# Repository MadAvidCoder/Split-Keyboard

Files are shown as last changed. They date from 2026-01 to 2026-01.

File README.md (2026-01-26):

# Split Keyboard
An ergonomic, wireless, split, low-profile keyboard I made for [Hack Club](https://hackclub.com/) [Blueprint](https://blueprint.hackclub.com/r/43?ref=r)! It is inspired by the Lily58 layout, but with column-staggering better optimised for my hands. It also features a thumb cluster designed for better ergonomics. Having recently started using a Mechcanical Keyboard, I was keen to design a Split Keyboard that was easy to transition to, so I elected to include a number row, and an additional 'function' column on each half.

You can read about my development journey [here](https://blueprint.hackclub.com/projects/10297).

render

## Key Features
- Wireless
- Split
- Customisable ZMK Firmware
- Column Staggered
- 54 Keys
- Thumb Clusters
- Low Profile Choc Switches
- RGB Backlight

## PCB
I designed the PCB using KiCad. I kept it simple, with only 2 layers. The two halves are (mostly) mirror-images of each other, and I used hierarchical sheets to easily keep the design matching.

### Schematic
schematic

### PCB Design
| Left | Right |
|---|---|
|||

## Firmware
I am using [ZMK Firmware](https://zmk.dev/) for this keyboard. The configuration files are in their own repo, linked to the `firmware` directory. I chose to keep the keymap simple, to make it easy to transition to from a standard keyboard. I have also included minimal extra features and config, as I want to experiment with that side of things, once I have actually built it.

## Case
I designed the case for the keyboard in Autodesk Fusion 360. It is a fairly simple design, which secures the PCB via 5 screws, and has a top plate to hold it all in place. The top half is secured with a number of locating pins. The two halves of the case are nearly identical, except for different placement of the capacitor cutout.

The case also features a cutout and location for the LiPo battery, so it can be easily secured. USB and charging access is via the edge above the thumb cluster.

|Top|Bottom|
|---|---|
|||

### Render
render

### Keycaps
To ensure they work well, I am using keycaps designed by other people. For the main keycaps, I am using the [LPX profile keycaps](https://github.com/levpopov/LPX), designed by [levpopov](https://github.com/levpopov).

For the thumb clusters, I have selected the [Choc Louder Keycaps](https://www.printables.com/model/1066117-choc-louder-keycaps-choc-and-mx-spacing) by [kooziecup](https://www.printables.com/@koozie). The dimpled profile should make them more comfortable for the thumbs to rest on.

## BOM
A more detailed csv BOM can be found in [BOM.csv](/BOM.csv). All prices are in USD, and rounded to 2 decimal places (although the total is based on un-rounded prices).

In some cases, items may have higher quantities than are actually needed, due to MOQ. However, I have done thorough research to ensure that these still work out as the cheapest option.

| Item | Qty. | Price (USD) | Ext. Price (USD) | Link |
|---|---|---|---|---|
| PCB | 1 | 12.55 | 12.55 | https://jlcpcb.com/ |
| Battery | 2 | 5.80 | 11.60 | https://ecocell.com.au/product/lipo-600-503040/ |
| nice!nano | 2 | 4.55 | 9.10 | https://www.aliexpress.com/item/1005007266900944.html |
| Hotswap Sockets | 70 | 0.11 | 7.70 | https://www.aliexpress.com/item/1005009312876316.html |
| Switches | 60 | 0.46 | 27.60 | https://www.aliexpress.com/item/1005008751312031.html |
| SK6812-MINI-E | 55 | 0.07 | 3.85 | https://www.lcsc.com/product-detail/C5149201.html |
| DMBJ PNLS8040-100M 10UH | 5 | 0.11 | 0.55 | https://www.lcsc.com/product-detail/C2849554.html |
| 100nF Capacitor | 100  | 0.01 | 1.00 | https://www.lcsc.com/product-detail/C49678.html |
| 10uF Capacitor | 10 | 0.02 | 0.20 | https://www.lcsc.com/product-detail/C32635.html |
| 22uF Capacitor | 10 | 0.02 | 0.20 | https://www.lcsc.com/product-detail/C98190.html |
| 470uF Capacitor | 10 | 0.04 | 0.40 | https://www.lcsc.com/product-detail/C2858856.html |
| 1N5819 Diode | 100  | 0.01 | 1.00 | https://www.lcsc.com/product-detail/C963381.html |
| SS34 Schottky Diode | 10 | 0.03 | 0.30 | https://www.lcsc.com/product-detail/C842788.html |
| 806k Resistor | 20 | <0.01 | 0.09 | https://www.lcsc.com/product-detail/C865659.html |
| 2M Resistor | 100  | <0.01 | 0.25 | https://www.lcsc.com/product-detail/C26112.html |
| 470R Resistor | 100  | <0.01 | 0.17 | https://www.lcsc.com/product-detail/C2907267.html |
| 2k Resistor | 100  | <0.01 | 0.18 | https://www.lcsc.com/product-detail/C2907248.html |
| 10k Resistor | 10 | 0.04 | 0.40 | https://www.lcsc.com/product-detail/C319942.html |
| 73.2k Resistor | 50 | 0.01 | 0.50 | https://www.lcsc.com/product-detail/C422816.html |
| 330R Resistor | 100  | <0.01 | 0.13 | https://www.lcsc.com/product-detail/C2907321.html |
| DW01A | 20 | 0.02 | 0.40 | https://www.lcsc.com/product-detail/C18164398.html |
| FS8205 | 10 | 0.05 | 0.50 | https://www.lcsc.com/product-detail/C2830320.html |
| MT3608 | 10 | 0.06 | 0.60 | https://www.lcsc.com/product-detail/C84817.html |
| LCSC Shipping | 1 | 12.72 | 12.72 | https://www.lcsc.com/ |
| EcoCell Shipping | 1 | 2.78 | 2.78 | https://ecocell.com.au/ |
| | | | | |
| **TOTAL** | | | | **$93.95 (USD)** |

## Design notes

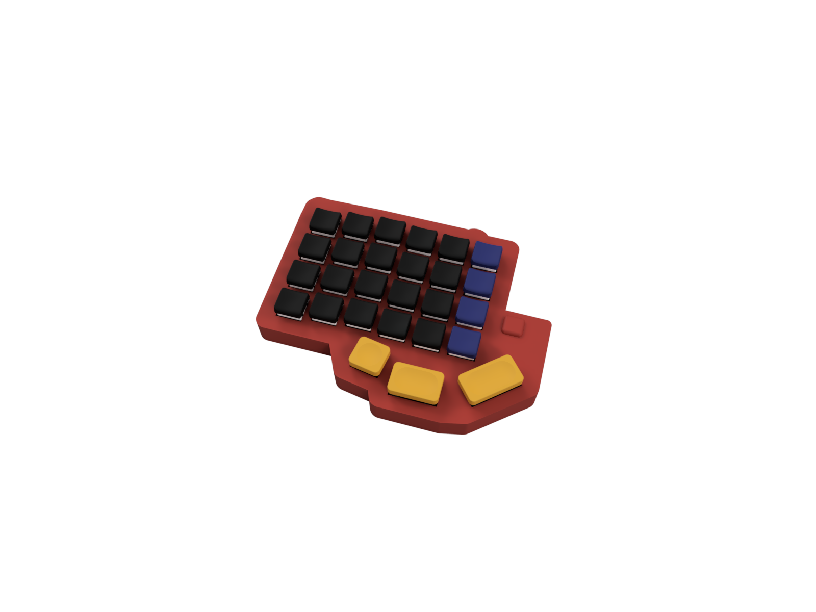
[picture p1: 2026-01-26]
case/render.png

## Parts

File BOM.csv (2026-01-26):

Part Name | Supplier | Link | Req. Qty | Total Qty | Unit Price | Total | Product Description
PCB | JLCPCB | https://jlcpcb.com/ | 1 | 5 | $2.51 | $12.55 | The PCB for the project
LiPo Battery | EcoCell | https://ecocell.com.au/product/lipo-600-503040/ | 2 | 2 | $5.80 | $11.60 | Rechargeable battery to power the keyboard
nice!nano | AliExpress | https://www.aliexpress.com/item/1005007266900944.html | 2 | 2 | $4.55 | $9.10 | Main microcontroller for the board (cheaper than xiao)
Hotswap Sockets | AliExpress | https://www.aliexpress.com/item/1005009312876316.html | 54 | 70 | $0.11 | $7.70 | Hotswap sockets, which make soldering easier
Switches | AliExpress | https://www.aliexpress.com/item/1005008751312031.html | 54 | 60 | $0.46 | $27.60 | There are a number of other options, but these seem the cheapest/best
SK6812-MINI-E | LCSC | https://www.lcsc.com/product-detail/C5149201.html | 54 | 55 | $0.07 | $3.85 | LED Backlight (reverse-mounted)
DMBJ PNLS8040-100M 10UH | LCSC | https://www.lcsc.com/product-detail/C2849554.html | 2 | 5 | $0.11 | $0.55 | Inductors for the 5V regulator
100nF Capacitor | LCSC | https://www.lcsc.com/product-detail/C49678.html | 56 | 100 | $0.01 | $1.00 | Used in various places, mostly as decoupling capacitors for the LEDs
10uF Capacitor | LCSC | https://www.lcsc.com/product-detail/C32635.html | 2 | 10 | $0.02 | $0.20 | Decoupling Capacitor for the battery protection ic
22uF Capacitor | LCSC | https://www.lcsc.com/product-detail/C98190.html | 4 | 10 | $0.02 | $0.20 | Decoupling capacitors for the 5V Boost converter
470uF Capacitor | LCSC | https://www.lcsc.com/product-detail/C2858856.html | 2 | 10 | $0.04 | $0.40 | Bulk Capacitor for the LEDs
1N5819 Diode | LCSC | https://www.lcsc.com/product-detail/C963381.html | 54 | 100 | $0.01 | $1.00 | Diodes for the keyboard matrix
SS34 Schottky Diode | LCSC | https://www.lcsc.com/product-detail/C842788.html | 2 | 10 | $0.03 | $0.30 | Schottky Diodes for low power loss in the boost converter
806k Resistor | LCSC | https://www.lcsc.com/product-detail/C865659.html | 2 | 20 | $0.00 | $0.00 | For the voltage divider
2M Resistor | LCSC | https://www.lcsc.com/product-detail/C26112.html | 2 | 100 | $0.00 | $0.00 | For the voltage divider
470R Resistor | LCSC | https://www.lcsc.com/product-detail/C2907267.html | 2 | 100 | $0.00 | $0.00 | For the BMS circuitry. Ordering so many because it works out far cheaper than other options
2k Resistor | LCSC | https://www.lcsc.com/product-detail/C2907248.html | 2 | 100 | $0.00 | $0.00 | For the BMS current detection. Ditto above as to why 100
10k Resistor | LCSC | https://www.lcsc.com/product-detail/C319942.html | 2 | 10 | $0.04 | $0.40 | Has to be low tolerance, for the 5v boost converter feedback
73k2 Resistor | LCSC | https://www.lcsc.com/product-detail/C422816.html | 2 | 50 | $0.01 | $0.50 | Has to be low tolerance, and they only had a few options, which had high MOQ
330R Resistor | LCSC | https://www.lcsc.com/product-detail/C2907321.html | 2 | 100 | $0.00 | $0.00 | For the LED Data lines, ordering a ton because its cheaper than one with low MOQ
DW01A | LCSC | https://www.lcsc.com/product-detail/C18164398.html | 2 | 20 | $0.02 | $0.40 | Battery Management IC (20 bc MOQ)
FS8205 | LCSC | https://www.lcsc.com/product-detail/C2830320.html | 2 | 10 | $0.05 | $0.50 | MOSFETs for the BMS
MT3608 | LCSC | https://www.lcsc.com/product-detail/C84817.html | 2 | 10 | $0.06 | $0.60 | 5V Boost Converter
LCSC Shipping | LCSC | https://www.lcsc.com/ | 1 | 1 | $12.72 | $12.72 | Shipping costs for all LCSC parts
EcoCell Shipping | EcoCell | https://ecocell.com.au/ | 1 | 1 | $2.78 | $2.78 | Shipping costs for all EcoCell parts
TOTAL |  |  |  |  |  | $93.95

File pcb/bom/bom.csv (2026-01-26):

Reference | Qty | Value | DNP | Exclude from BOM | Exclude from Board | Footprint | Datasheet
C1,C2,C9,C10,C11,C12,C13,C14,C15,C16,C17,C18,C19,C20,C21,C22,C23,C24,C25,C26,C27,C28,C29,C30,C31,C32,C33,C34,C35,C36,C37,C38,C39,C40,C41,C42,C43,C44,C45,C46,C47,C48,C49,C50,C51,C52,C53,C54,C55,C56,C60,C61,C62,C66,C67,C68 | 56 | 100n |  |  |  | Capacitor_SMD:C_0805_2012Metric_Pad1.18x1.45mm_HandSolder | ~
C3,C4 | 2 | 10u |  |  |  | Capacitor_SMD:C_0805_2012Metric_Pad1.18x1.45mm_HandSolder | ~
C5,C6,C7,C8 | 4 | 22u |  |  |  | Capacitor_SMD:C_0805_2012Metric_Pad1.18x1.45mm_HandSolder | ~
C57,C58 | 2 | 470u |  |  |  | Capacitor_SMD:CP_Elec_6.3x7.7 | ~
D1,D2,D3,D4,D5,D6,D7,D8,D9,D10,D11,D12,D13,D14,D15,D16,D17,D18,D19,D20,D21,D22,D23,D24,D25,D26,D27,D28,D29,D30,D31,D32,D33,D34,D35,D36,D37,D38,D39,D40,D41,D42,D43,D44,D45,D46,D47,D48,D49,D50,D51,D52,D53,D54 | 54 | D |  |  |  | Diode_SMD:D_SOD-123 | ~
D55,D56 | 2 | SS34 |  |  |  | Diode_SMD:D_SMA | https://www.vishay.com/docs/88751/ss32.pdf
H1,H2,H15 | 3 | MountingHole |  | Excluded from BOM |  | Panelization:mouse-bite-3mm-slot | ~
H3,H4,H5,H6,H7,H8,H9,H10,H11,H12 | 10 | MountingHole |  | Excluded from BOM |  | MountingHole:MountingHole_3.2mm_M3 | ~
L1,L2 | 2 | PNLS8040-100M 10UH |  |  |  | Inductor_SMD:L_Cenker_CKCS8040 | ~
LED1,LED2,LED3,LED4,LED5,LED6,LED7,LED8,LED9,LED10,LED11,LED12,LED25,LED26,LED27,LED28,LED29,LED30,LED31,LED32,LED33,LED34,LED35,LED36,LED52,LED53,LED54,LED58,LED59,LED60 | 30 | choc_SK6812MINI-E |  |  |  | PCM_marbastlib-choc:LED_choc_6028R
LED13,LED14,LED15,LED16,LED17,LED18,LED19,LED20,LED21,LED22,LED23,LED24,LED37,LED38,LED39,LED40,LED41,LED42,LED43,LED44,LED45,LED46,LED47,LED48 | 24 | choc_SK6812MINI-E |  |  |  | PCM_marbastlib-choc:LED_choc_6028R-ROT
R1,R2 | 2 | 806k |  |  |  | Resistor_SMD:R_0805_2012Metric_Pad1.20x1.40mm_HandSolder | ~
R3,R4 | 2 | 2M |  |  |  | Resistor_SMD:R_0805_2012Metric_Pad1.20x1.40mm_HandSolder | ~
R5,R6 | 2 | 470R |  |  |  | Resistor_SMD:R_0805_2012Metric_Pad1.20x1.40mm_HandSolder | ~
R7,R8 | 2 | 2k |  |  |  | Resistor_SMD:R_0805_2012Metric_Pad1.20x1.40mm_HandSolder | ~
R9,R10 | 2 | 10k |  |  |  | Resistor_SMD:R_0805_2012Metric_Pad1.20x1.40mm_HandSolder | ~
R11,R12 | 2 | 73k2 |  |  |  | Resistor_SMD:R_0805_2012Metric_Pad1.20x1.40mm_HandSolder | ~
R13,R14 | 2 | 330R |  |  |  | Resistor_SMD:R_0805_2012Metric_Pad1.20x1.40mm_HandSolder | ~
SW1,SW2,SW3,SW4,SW5,SW6,SW7,SW8,SW9,SW10,SW11,SW12,SW13,SW14,SW15,SW16,SW17,SW18,SW19,SW20,SW21,SW22,SW23,SW24,SW25,SW26,SW27,SW28,SW29,SW30,SW31,SW32,SW33,SW34,SW35,SW36,SW37,SW38,SW39,SW40,SW41,SW42,SW43,SW44,SW45,SW46,SW47,SW48,SW53,SW54 | 50 | SW_Push |  |  |  | PCM_marbastlib-choc:SW_choc_v1_HS_CPG135001S30_1u | ~
SW49,SW50 | 2 | SW_Push |  |  |  | marbastlib-choc:SW_choc_v1_HS_CPG135001S30_1.75u | ~
SW51,SW52 | 2 | SW_Push |  |  |  | marbastlib-choc:SW_choc_v1_HS_CPG135001S30_1.5u | ~
TP1,TP2 | 2 | BAT |  |  |  | TestPoint:TestPoint_Pad_D2.0mm | ~
TP3,TP4 | 2 | GND |  |  |  | TestPoint:TestPoint_Pad_D2.0mm | ~
U3,U4 | 2 | DW01A |  |  |  | Package_TO_SOT_SMD:SOT-23-6 | https://hmsemi.com/downfile/DW01A.PDF
U5,U6 | 2 | FS8205 |  |  |  | Package_TO_SOT_SMD:SOT-23-6 | https://datasheet.lcsc.com/szlcsc/Fortune-Semicon-FS8205_C32254.pdf
U7,U8 | 2 | MT3608 |  |  |  | Package_TO_SOT_SMD:SOT-23-6 | https://www.olimex.com/Products/Breadboarding/BB-PWR-3608/resources/MT3608.pdf
U9,U10 | 2 | nice_nano |  | Excluded from BOM |  | PCM_marbastlib-xp-promicroish:nice_nano_AH_USBup | https://nicekeyboards.com/docs/nice-nano/pinout-schematic

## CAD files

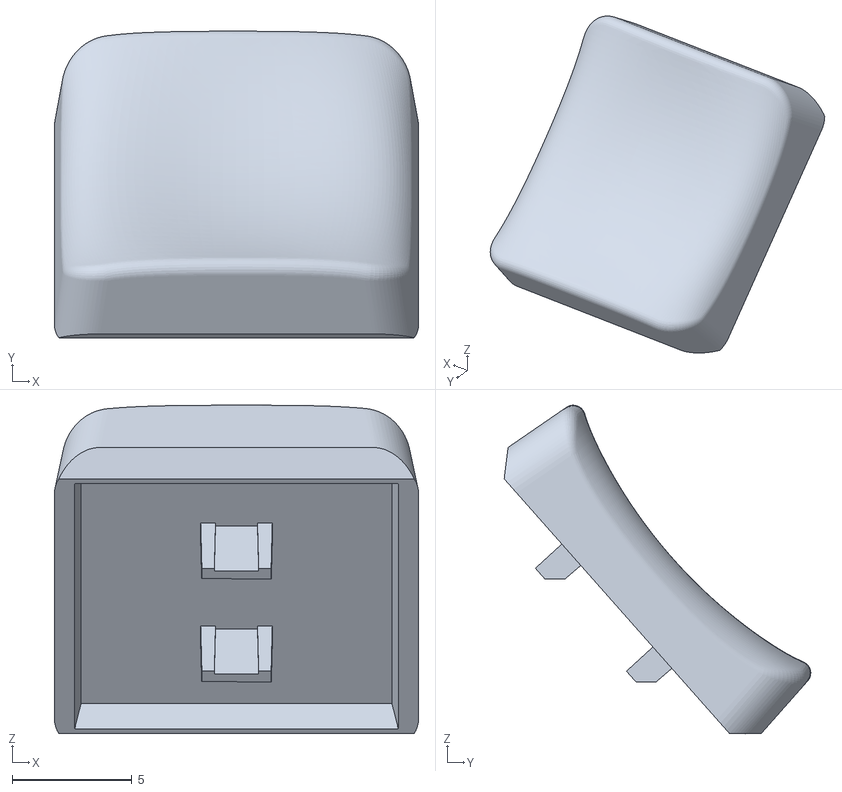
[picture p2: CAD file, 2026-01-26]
case/Main Keycap.stl
15.2 x 12.8 x 13.7

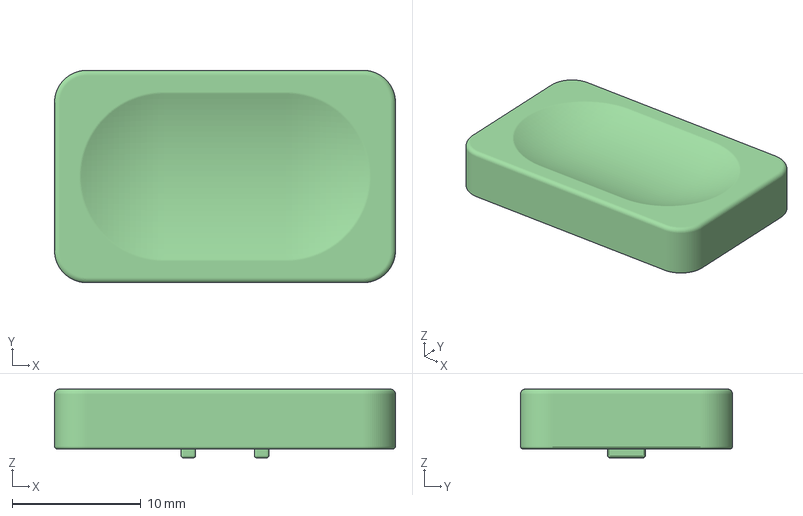
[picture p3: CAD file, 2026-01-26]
case/Thumb Keycap - 1.5u.3mf
26.5 x 16.5 x 5.35 mm

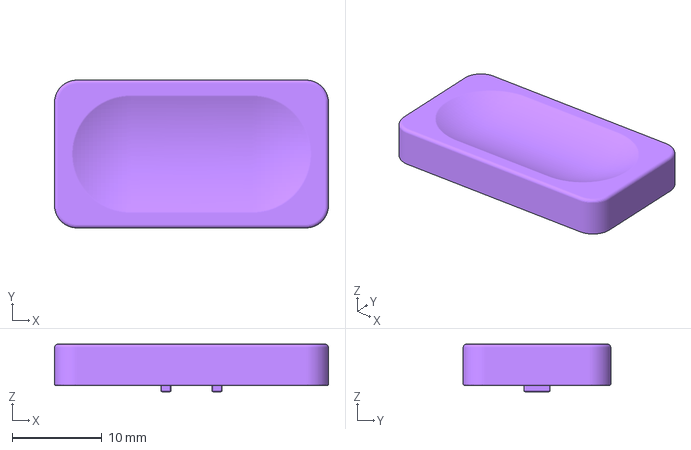
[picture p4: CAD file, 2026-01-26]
case/Thumb Keycap - 1.75u.3mf
30.6 x 16.5 x 5.35 mm

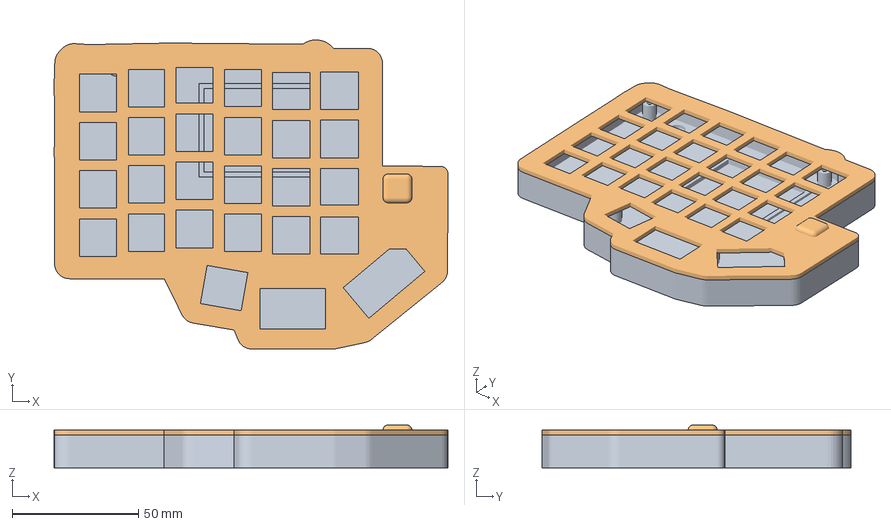
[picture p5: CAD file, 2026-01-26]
case/Case Left.3mf
155.8 x 122.2 x 17.0 mm

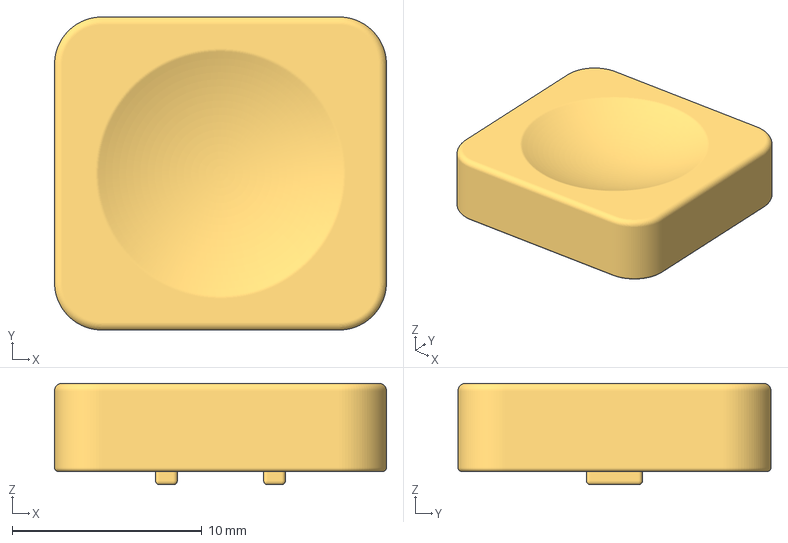
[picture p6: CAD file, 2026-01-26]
case/Thumb Keycap - 1u.3mf
17.5 x 16.5 x 5.35 mm

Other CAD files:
case/Case Right.3mf

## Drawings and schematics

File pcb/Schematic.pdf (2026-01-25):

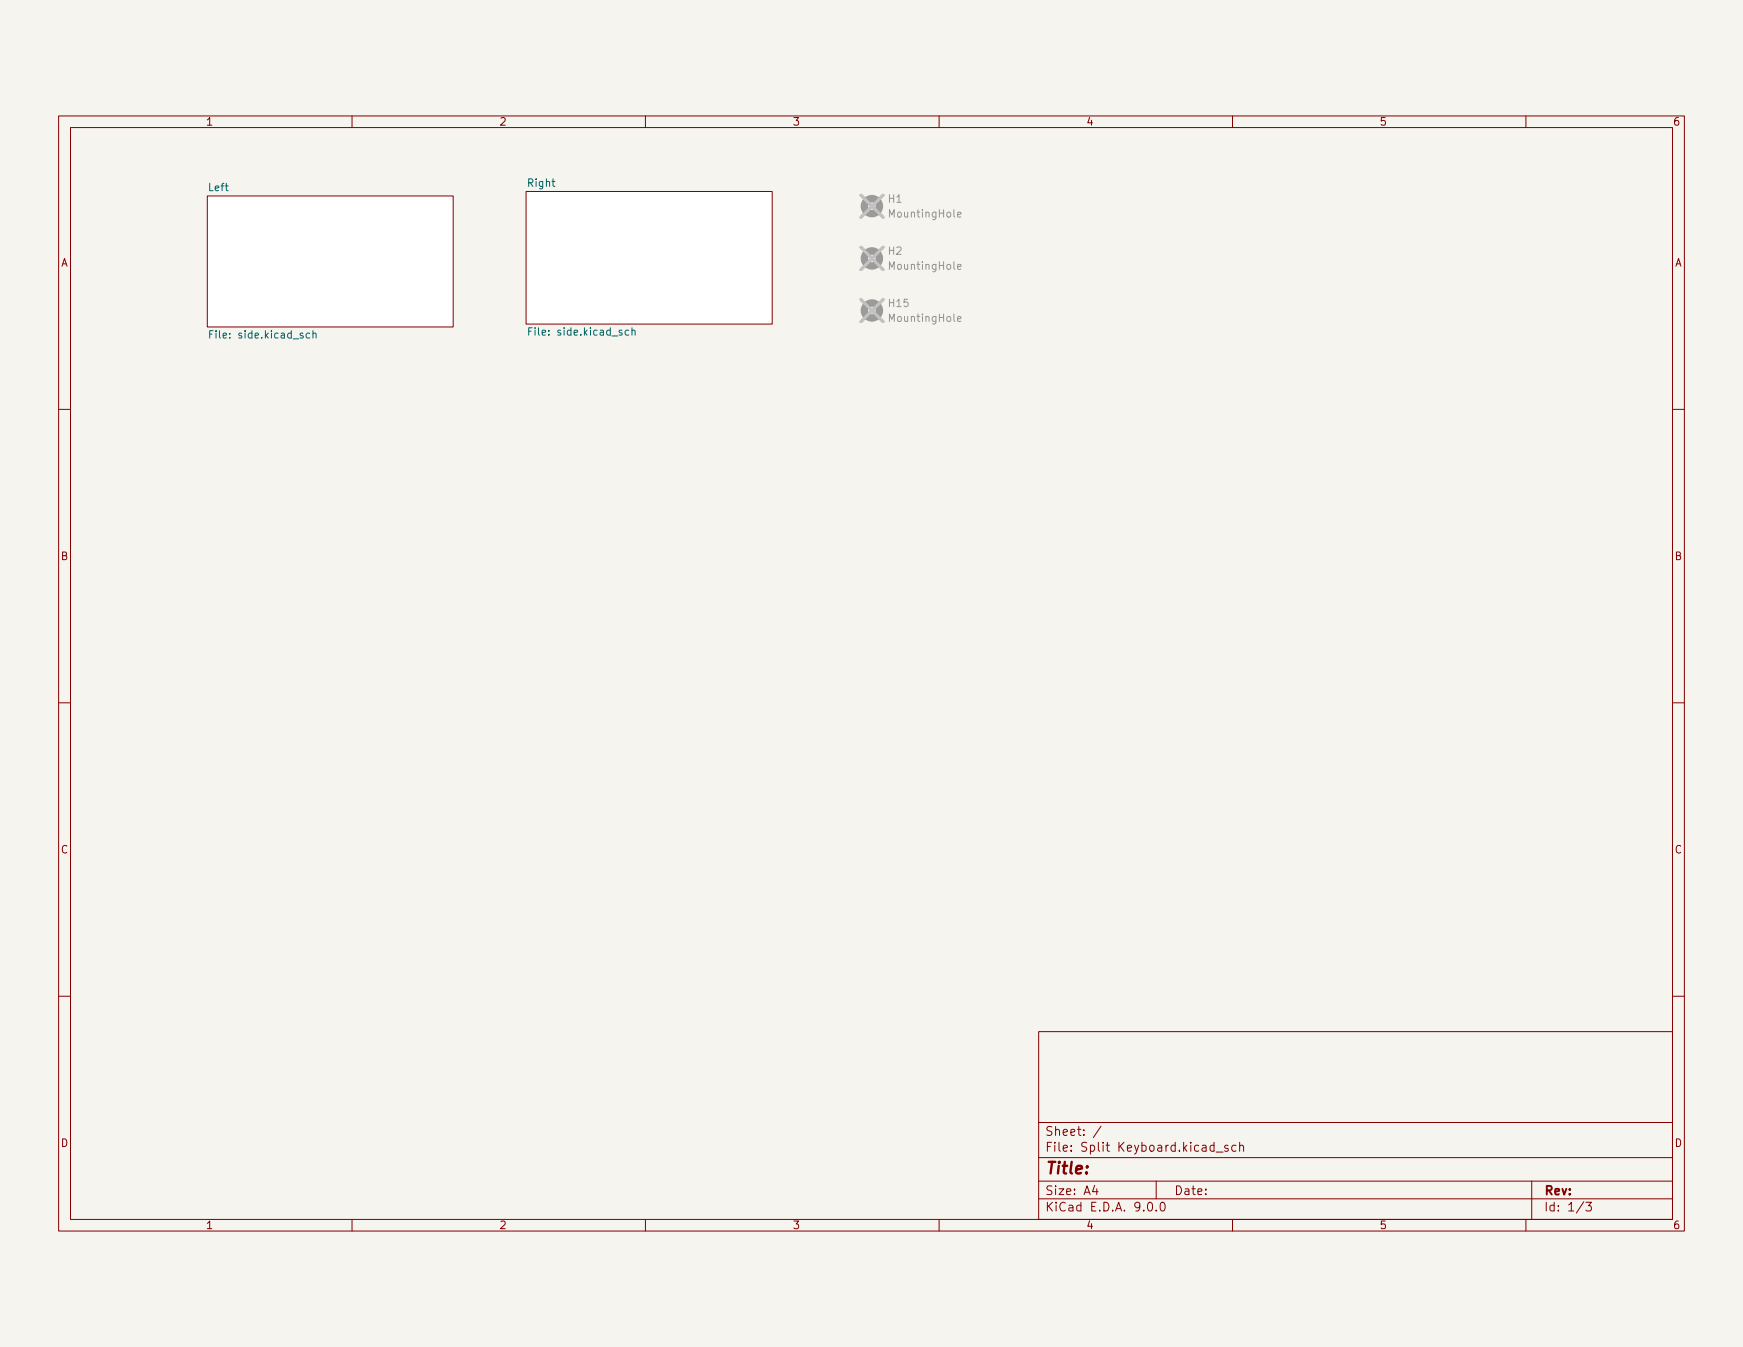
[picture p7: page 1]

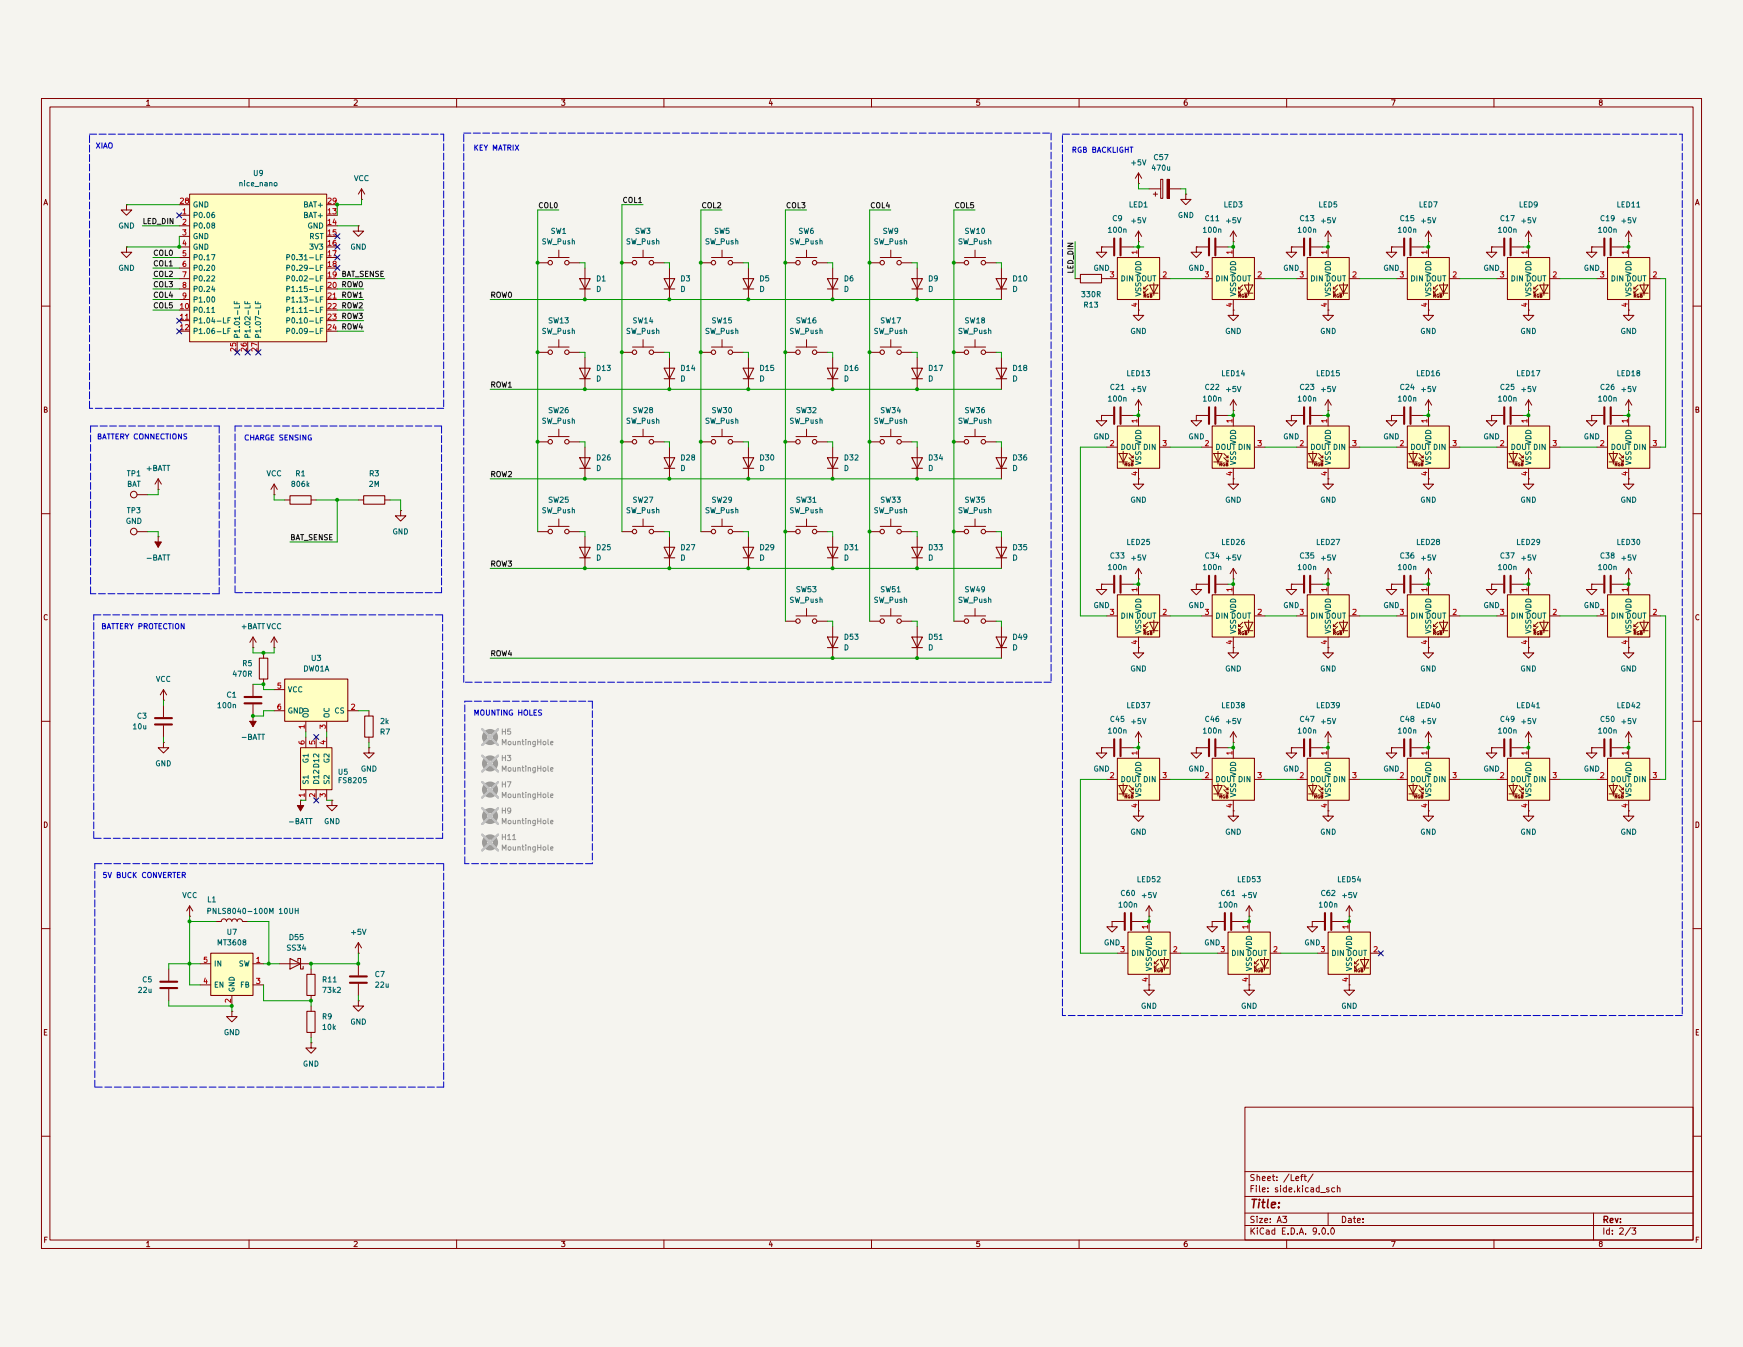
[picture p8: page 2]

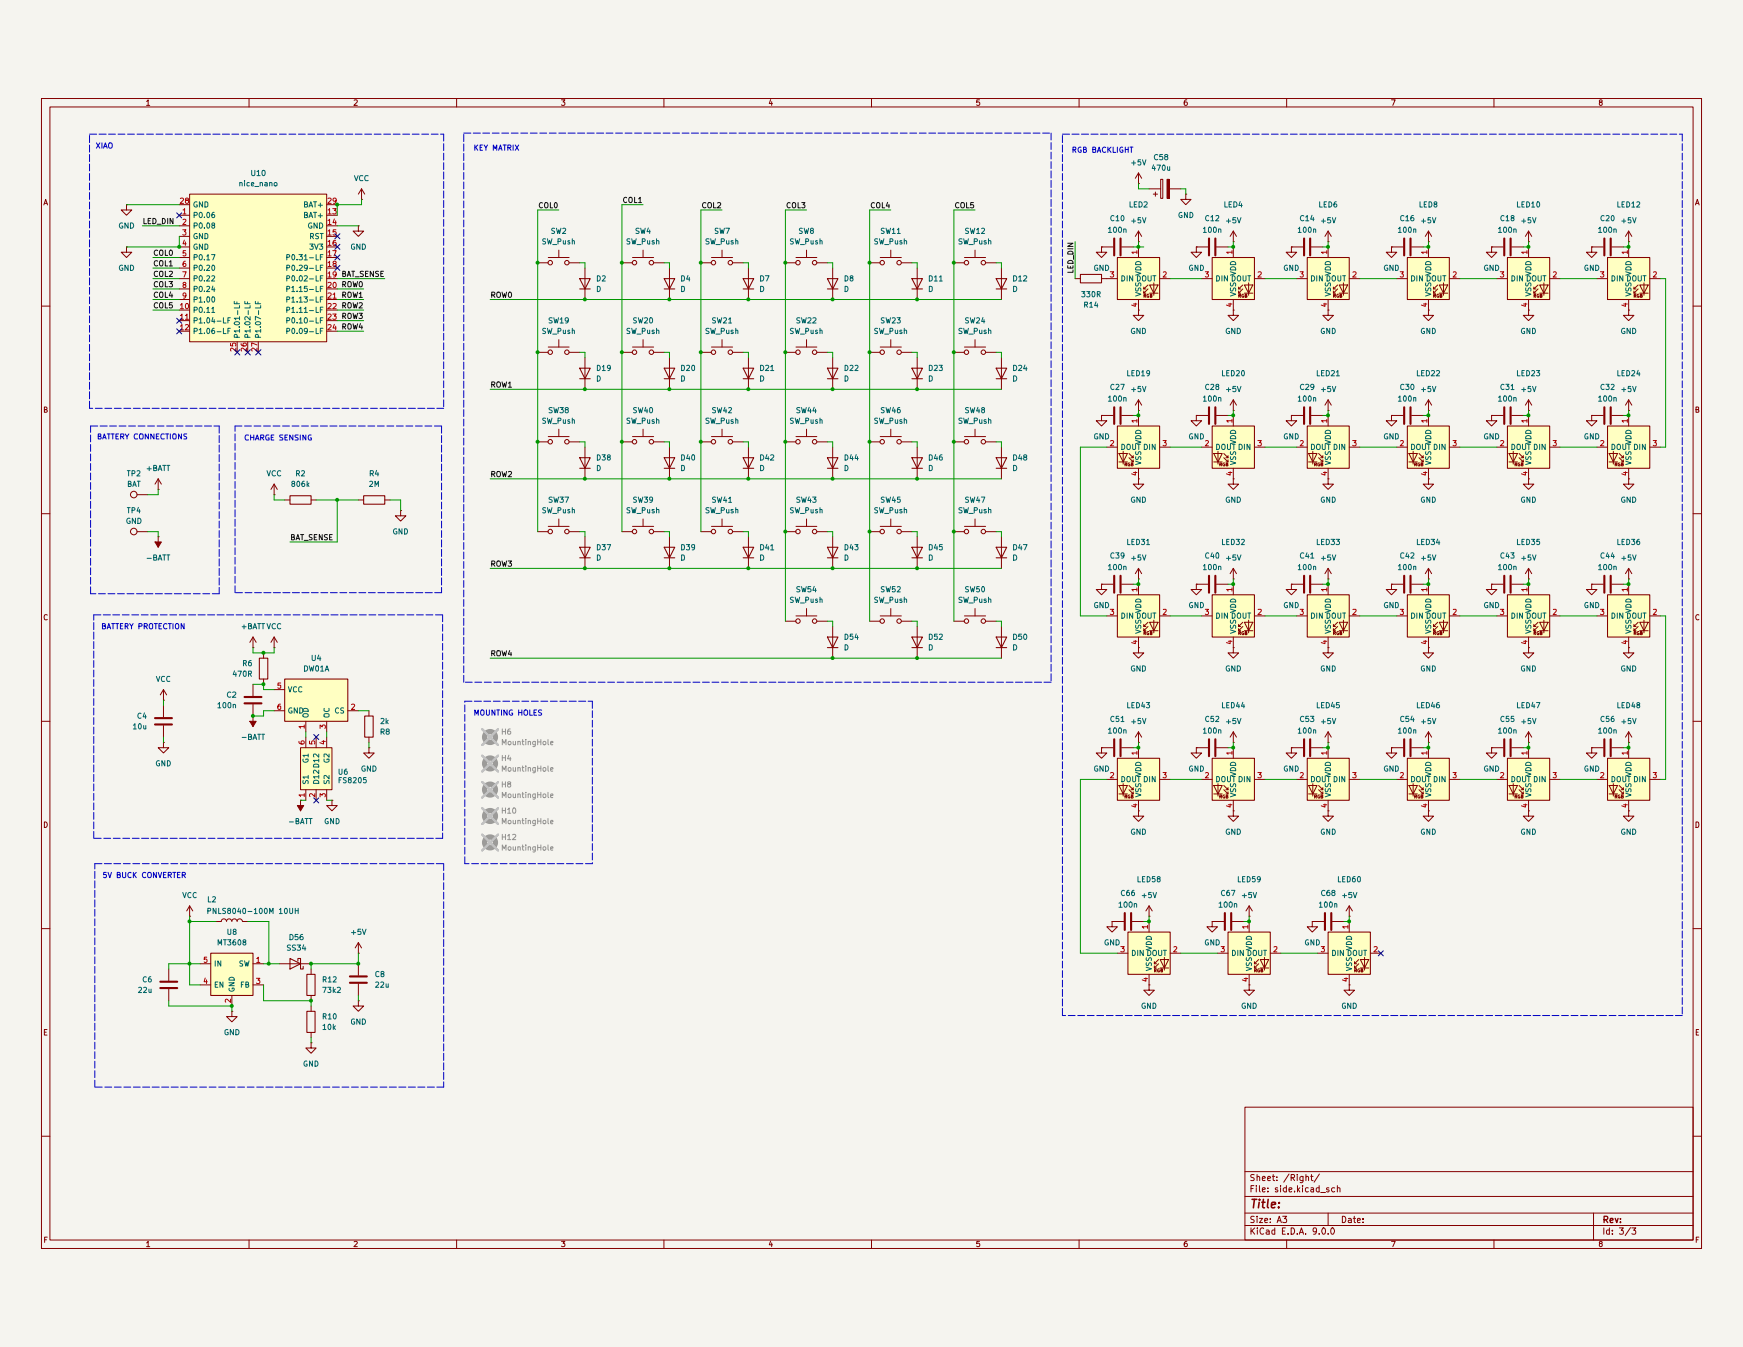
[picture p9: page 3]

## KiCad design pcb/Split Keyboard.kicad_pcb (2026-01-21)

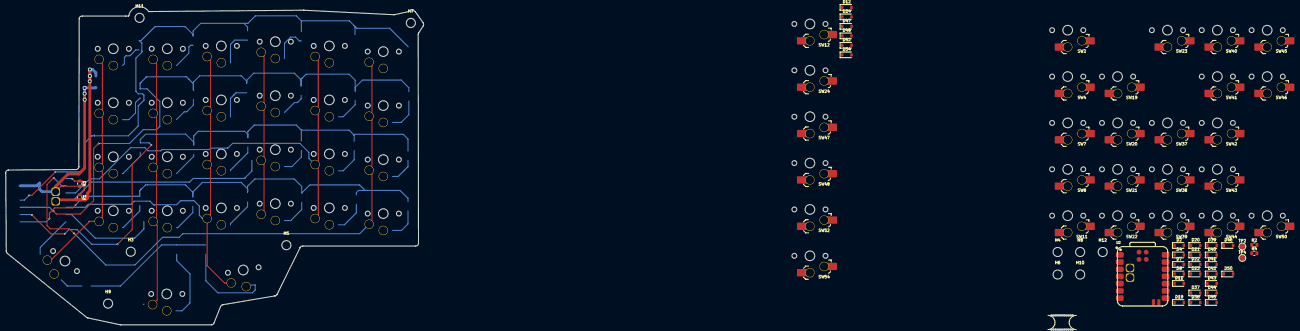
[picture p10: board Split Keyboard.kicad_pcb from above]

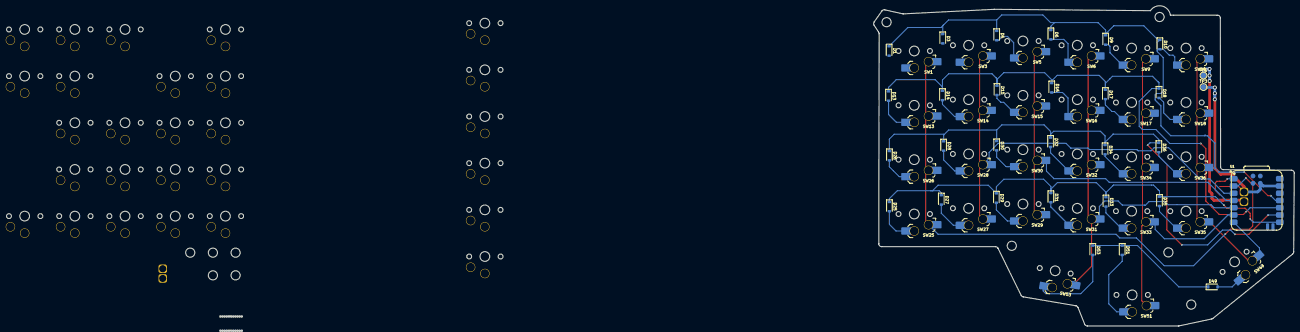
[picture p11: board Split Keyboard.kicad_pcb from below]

Board: 2 copper layers, 147.4 x 112.2 mm, 131 parts (57 on the bottom side), 80 nets.

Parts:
D1, D2, D3, D4, D5, D6, D7, D8, D9, D10, D11, D12, D13, D14, D15, D16, D17, D18, D19, D20, D21, D22, D23, D24, D25, D26, D27, D28, D29, D30, D31, D32, D33, D34, D35, D36, D37, D38, D39, D40, D41, D42, D43, D44, D45, D46, D47, D48, D49, D50, D51, D52, D53, D54: D; D_SOD-123
H1, H2, H15: MountingHole; mouse-bite-5mm-slot
H3, H4, H5, H6, H7, H8, H9, H10, H11, H12: MountingHole; MountingHole_3.2mm_M3
R1, R2: 806k; R_0805_2012Metric
R3, R4: 2M; R_0805_2012Metric
SW1, SW2, SW3, SW4, SW5, SW6, SW7, SW8, SW9, SW10, SW11, SW12, SW13, SW14, SW15, SW16, SW17, SW18, SW19, SW20, SW21, SW22, SW23, SW24, SW25, SW26, SW27, SW28, SW29, SW30, SW31, SW32, SW33, SW34, SW35, SW36, SW37, SW38, SW39, SW40, SW41, SW42, SW43, SW44, SW45, SW46, SW47, SW48, SW53, SW54: SW_Push; SW_choc_v1_HS_CPG135001S30_1u
SW49, SW50: SW_Push; SW_choc_v1_HS_CPG135001S30_1.75u
SW51, SW52: SW_Push; SW_choc_v1_HS_CPG135001S30_1.5u
TP1, TP2: BAT; TestPoint_Pad_D2.0mm
TP3, TP4: GND; TestPoint_Pad_D2.0mm
U1, U2: XIAO-nRF52840-SMD; modified-XIAO-nRF52840-SMD

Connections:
/Left/BAT_SENSE: R1.1, R3.1, U1.1 (P0.02_A0_D0)
/Left/COL0: SW1.1, SW13.1, SW25.1, SW26.1, U1.2 (P0.03_A1_D1)
/Left/COL1: SW3.1, SW14.1, SW27.1, SW28.1, U1.3 (P0.28_A2_D2)
/Left/COL2: SW5.1, SW15.1, SW29.1, SW30.1, U1.4 (P0.29_A3_D3)
/Left/COL3: SW6.1, SW16.1, SW31.1, SW32.1, SW53.1, U1.5 (P0.04_A4_D4_SDA)
/Left/COL4: SW9.1, SW17.1, SW33.1, SW34.1, SW51.1, U1.6 (P0.05_A5_D5_SCL)
/Left/COL5: SW10.1, SW18.1, SW35.1, SW36.1, SW49.1, U1.7 (P1.11_D6_TX)
/Left/ROW0: D1.1 (K), D3.1 (K), D5.1 (K), D6.1 (K), D9.1 (K), D10.1 (K), U1.11 (P1.15_D10_MOSI)
/Left/ROW1: D13.1 (K), D14.1 (K), D15.1 (K), D16.1 (K), D17.1 (K), D18.1 (K), U1.10 (P1.14_D9_MISO)
/Left/ROW2: D26.1 (K), D28.1 (K), D30.1 (K), D32.1 (K), D34.1 (K), D36.1 (K), U1.9 (P1.13_D8_SCK)
/Left/ROW3: D25.1 (K), D27.1 (K), D29.1 (K), D31.1 (K), D33.1 (K), D35.1 (K), U1.8 (P1.12_D7_RX)
/Left/ROW4: D49.1 (K), D51.1 (K), D53.1 (K)
/Right/BAT_SENSE: R2.1, R4.1, U2.1 (P0.02_A0_D0)
/Right/COL0: SW2.1, SW19.1, SW37.1, SW38.1, U2.2 (P0.03_A1_D1)
/Right/COL1: SW4.1, SW20.1, SW39.1, SW40.1, U2.3 (P0.28_A2_D2)
/Right/COL2: SW7.1, SW21.1, SW41.1, SW42.1, U2.4 (P0.29_A3_D3)
/Right/COL3: SW8.1, SW22.1, SW43.1, SW44.1, SW54.1, U2.5 (P0.04_A4_D4_SDA)
/Right/COL4: SW11.1, SW23.1, SW45.1, SW46.1, SW52.1, U2.6 (P0.05_A5_D5_SCL)
/Right/COL5: SW12.1, SW24.1, SW47.1, SW48.1, SW50.1, U2.7 (P1.11_D6_TX)
/Right/ROW0: D2.1 (K), D4.1 (K), D7.1 (K), D8.1 (K), D11.1 (K), D12.1 (K), U2.11 (P1.15_D10_MOSI)
/Right/ROW1: D19.1 (K), D20.1 (K), D21.1 (K), D22.1 (K), D23.1 (K), D24.1 (K), U2.10 (P1.14_D9_MISO)
/Right/ROW2: D38.1 (K), D40.1 (K), D42.1 (K), D44.1 (K), D46.1 (K), D48.1 (K), U2.9 (P1.13_D8_SCK)
/Right/ROW3: D37.1 (K), D39.1 (K), D41.1 (K), D43.1 (K), D45.1 (K), D47.1 (K), U2.8 (P1.12_D7_RX)
/Right/ROW4: D50.1 (K), D52.1 (K), D54.1 (K)
GND: R3.2, R4.2, TP3.1, TP4.1, U1.13 (GND), U1.16 (GND), U1.22 (GND), U2.13 (GND), U2.16 (GND), U2.22 (GND)
unnamed: D1.2 (A), SW1.2
unnamed: D2.2 (A), SW2.2
unnamed: D3.2 (A), SW3.2
unnamed: D4.2 (A), SW4.2
unnamed: D5.2 (A), SW5.2
unnamed: D6.2 (A), SW6.2
unnamed: D7.2 (A), SW7.2
unnamed: D8.2 (A), SW8.2
unnamed: D9.2 (A), SW9.2
unnamed: D10.2 (A), SW10.2
unnamed: D11.2 (A), SW11.2
unnamed: D12.2 (A), SW12.2
unnamed: D13.2 (A), SW13.2
unnamed: D14.2 (A), SW14.2
unnamed: D15.2 (A), SW15.2
unnamed: D16.2 (A), SW16.2
unnamed: D17.2 (A), SW17.2
unnamed: D18.2 (A), SW18.2
unnamed: D19.2 (A), SW19.2
unnamed: D20.2 (A), SW20.2
unnamed: D21.2 (A), SW21.2
unnamed: D22.2 (A), SW22.2
unnamed: D23.2 (A), SW23.2
unnamed: D24.2 (A), SW24.2
unnamed: D25.2 (A), SW25.2
unnamed: D26.2 (A), SW26.2
unnamed: D27.2 (A), SW27.2
unnamed: D28.2 (A), SW28.2
unnamed: D29.2 (A), SW29.2
unnamed: D30.2 (A), SW30.2
unnamed: D31.2 (A), SW31.2
unnamed: D32.2 (A), SW32.2
unnamed: D33.2 (A), SW33.2
unnamed: D34.2 (A), SW34.2
unnamed: D35.2 (A), SW35.2
unnamed: D36.2 (A), SW36.2
unnamed: D37.2 (A), SW37.2
unnamed: D38.2 (A), SW38.2
unnamed: D39.2 (A), SW39.2
unnamed: D40.2 (A), SW40.2
unnamed: D41.2 (A), SW41.2
unnamed: D42.2 (A), SW42.2
unnamed: D43.2 (A), SW43.2
unnamed: D44.2 (A), SW44.2
unnamed: D45.2 (A), SW45.2
unnamed: D46.2 (A), SW46.2
unnamed: D47.2 (A), SW47.2
unnamed: D48.2 (A), SW48.2
unnamed: D49.2 (A), SW49.2
unnamed: D50.2 (A), SW50.2
unnamed: D51.2 (A), SW51.2
unnamed: D52.2 (A), SW52.2
unnamed: D53.2 (A), SW53.2
unnamed: D54.2 (A), SW54.2
VBAT: R1.2, R2.2, TP1.1, TP2.1, U1.15 (BAT), U2.15 (BAT)

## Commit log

2026-01-20 Create KiCad Project
    Created the main kicad project
    [Split Keyboard.kicad_pcb, Split Keyboard.kicad_sch]
2026-01-20 Update gitignore
    Updated the gitignore file to include Kicad temporary lock files
2026-01-20 Create Schematics
    Created the blank schematic, ready to be edited
2026-01-20 Design schematic
    I designed the base schematic for the keyboard, and assigned parts and footprints for everything
    [Split Keyboard.kicad_sch, side.kicad_sch]
2026-01-21 Add BMS and LEDs
    Added a Battery Management system and some RGB LED backlight
    [Split Keyboard.kicad_pcb, side.kicad_sch]
2026-01-22 Add other half
    Designed, Placed and Routed the other half of the PCB
    [Split Keyboard.kicad_sch, side.kicad_sch]
2026-01-24 Finished Designing PCB
    Finished Desiging the PCB and exported gerbers for manufacturing
    [Split Keyboard-B_Cu.gbr, Split Keyboard-B_Mask.gbr, Split Keyboard-B_Paste.gbr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]
2026-01-25 Export Schematic
    Exported the Schematic to a PDF for easier review
2026-01-25 Add 3d models
    Added 3d models to the PCB and exported
2026-01-26 Add Case
    Added the CAD files for the case
    [Case Left.3mf, Case Right.3mf, Main Keycap.stl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]
2026-01-26 Add BOMs
    Added the BOM for the project
    [BOM.csv, bom.csv]
2026-01-26 Add total cost
    Added the total cost to the BOM
